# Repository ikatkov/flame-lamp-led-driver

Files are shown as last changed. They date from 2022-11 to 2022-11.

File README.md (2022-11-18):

# (Power) Inductor saturation current tester

~60A max current. Power supply 5-25V.
Based on http://elm-chan.org/works/lchk/report.html

You will need an oscilloscope to take measurements.

# Theory

Once powered, the capacitor bank charges up. The circuit fires off a variable-width pulse into the MOSFET gate. MOSFET turns ON and short-circuits the inductor to the capacitor power bank. The current starts to rise linearly until the saturation point is reached. Once the inductor is saturated, it behaves like an ohmic piece of wire, and the current increases exponentially until the pulse is over, and the MOSFET is switched OFF. Saturation is a knee, not a sharp point. So you have some wiggle room in what current you designate as a "saturation current." Before the saturation point and including the "knee region," inductance will be higher than labeled. Once saturated sufficiently - inductance will drop.

Commercial manufacturers pick the point where a power inductor loses 20-30% of its labeled inductance. One can safely operate inductors at x1.3-1.5 their knee point.

You take voltage drop measurements across 0.1 Ohm resistor, multiply by 10 and get current in Amps flowing through your inductor under test. `I = V*10`

You can also compute actual inductance be taking your supply voltage and dividing by the voltage slope. 
`L = Vs * Δt / ΔI`. 

# Practical operations

See "sort-of" instructions video https://www.youtube.com/watch?v=3Y_WcuIenSM
Notice that although their PCB is labeled 1us..50us. It's impossible to get a positive pulse width of less than 10uS with NE555. One can replace it with other astable timers ICs, but you need a separate MOSFET driving circuitry. NE555 raising and falling times ~350ns, with a max current of 200mA, which is not enough to quickly switch power MOSFETs ON/OFF. The MOSFET will be in its linear region for some time. Therefore the trigger pulse is set to ~50Hz, letting MOSFET cool down between pulses. Also, notice that the current sense shunt, capacitor bank ESR and traces resistance limits max current to ~56A.
You would want to rig some sort of replacable solder-pads on the top of the PCB, so you can finger-press small SMD inductors to it and solder large ones to take measurements. There are header holes for this.

* Unplug the power
* Turn the potentiometer all the way counterclockwise. Set the duration selector jumper to the shortest range. 
* Connect oscilloscope probes
* Plug the power
* Look at the oscilloscope
* Turn the potentiometer clockwise (increasing the pulse width) until you see the saturation knee
* If you still see a linear ramp, unplug, change the duration selector jumper to the next position, turn the potentiometer all the way counterclockwise and repeat
* Take measurements

Knee

Schematic

# Manufacturing

PCB
Top view
[PCB STEP model](main.step)

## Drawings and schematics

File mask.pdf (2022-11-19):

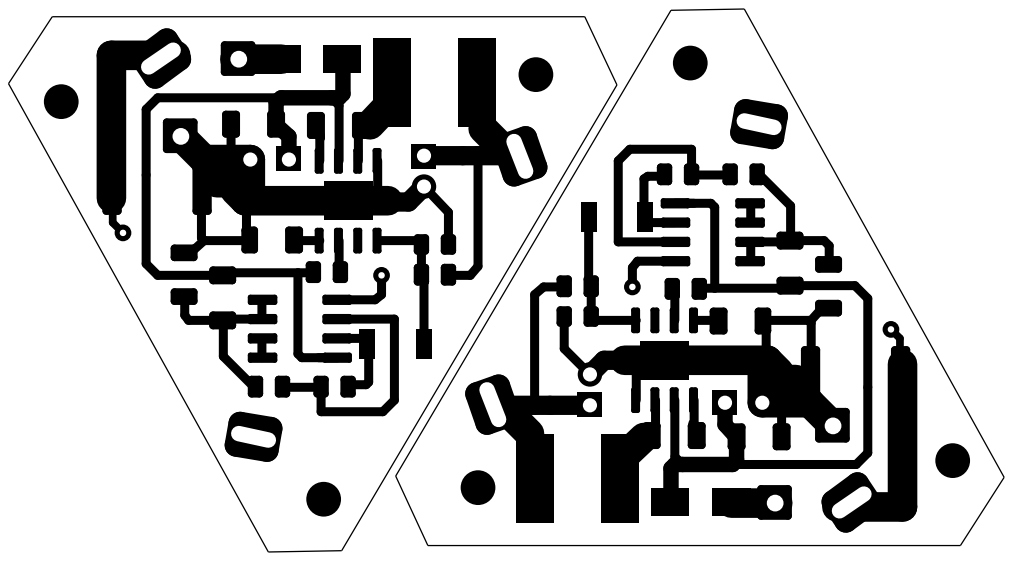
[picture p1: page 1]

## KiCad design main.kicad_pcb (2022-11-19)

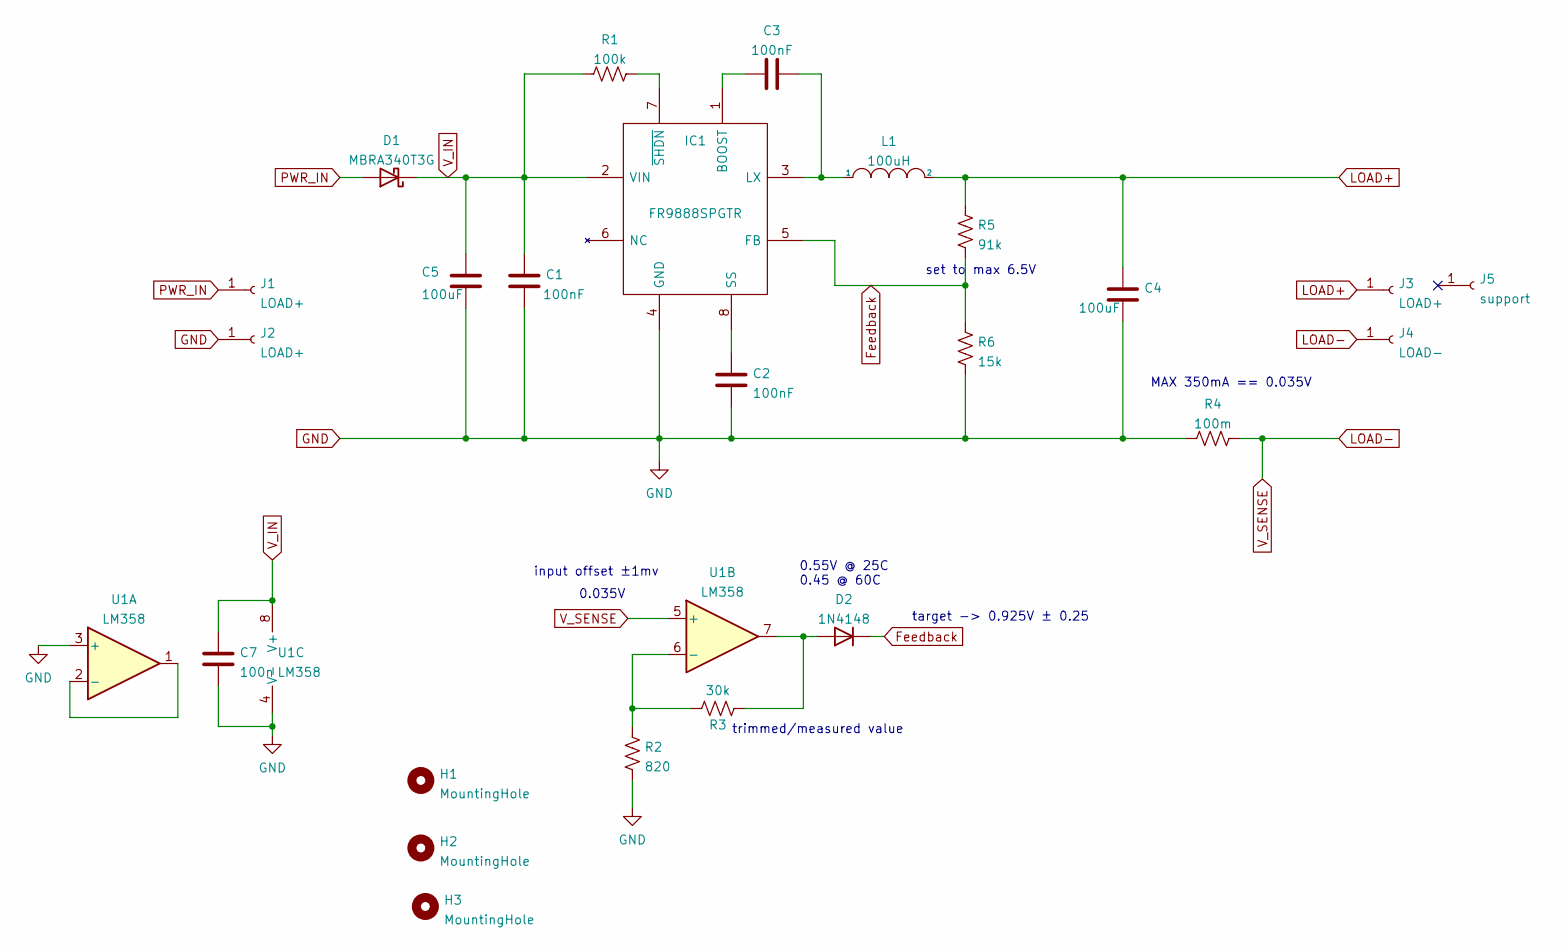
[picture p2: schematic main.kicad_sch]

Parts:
C1, C2, C3: 100nF; C_1206_3216Metric
C4: 100uF; CP_Radial_D5.0mm_P2.00mm
C5: 100uF; CP_Radial_D6.3mm_P2.50mm
C7: 100n; C_1206_3216Metric
D1: MBRA340T3G; D_SMA
D2: 1N4148; D_4148_SMD
H1, H2, H3: MountingHole; MountingHole_2.2mm_M2
IC1: FR9888SPGTR; SOIC-8-1EP_3.9x4.9mm_P1.27mm_EP2.514x3.2mm; Manufacturer_Part_Number FR9888SPGTR
J1, J2: LOAD+; SolderWire-0.5sqmm_1x01_D0.9mm_OD2.3mm
J3: LOAD+; SolderWire-slot
J4: LOAD-; SolderWire-slot
J5: support; SolderWire-slot
L1: 100uH; L_Taiyo-Yuden_NR-60xx_HandSoldering
R1: 100k; R_0805_2012Metric
R2: 820; R_0805_2012Metric
R3: 30k; R_0805_2012Metric
R4: 100m; R_2512_6332Metric
R5: 91k; R_0805_2012Metric
R6: 15k; R_0805_2012Metric
U1: LM358; SOIC-8_3.9x4.9mm_P1.27mm

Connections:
Feedback: D2.1 (K), IC1.5 (FB), R5.1, R6.2
GND: C1.2, C2.2, C4.2, C5.2, C7.2, IC1.4 (GND), J2.1, R2.2, R4.1, R6.1, U1.3 (+), U1.4 (V-)
LOAD+: C4.1, J3.1, L1.2, R5.2
LOAD-: J4.1, R4.2, U1.5 (+)
unnamed: C2.1, IC1.8 (SS)
unnamed: C3.1, IC1.3 (LX), L1.1
unnamed: C3.2, IC1.1 (BOOST)
unnamed: D2.2 (A), R3.2, U1.7
unnamed: IC1.7 (~SHDN), R1.2
unnamed: R2.1, R3.1, U1.6 (-)
unnamed: U1.1, U1.2 (-)
PWR_IN: D1.2 (A), J1.1
V_IN: C1.1, C5.1, C7.1, D1.1 (K), IC1.2 (VIN), R1.1, U1.8 (V+)

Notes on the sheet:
set to max 6.5V
0.035V
0.55V @ 25C 0.45 @ 60C
MAX 350mA == 0.035V
target -> 0.925V ± 0.25
trimmed/measured value
input offset ±1mv

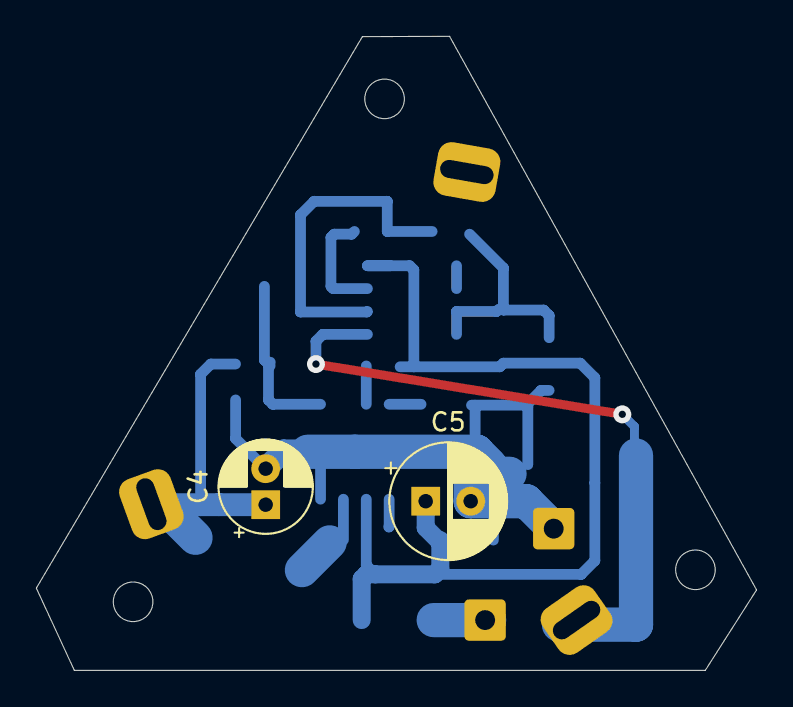
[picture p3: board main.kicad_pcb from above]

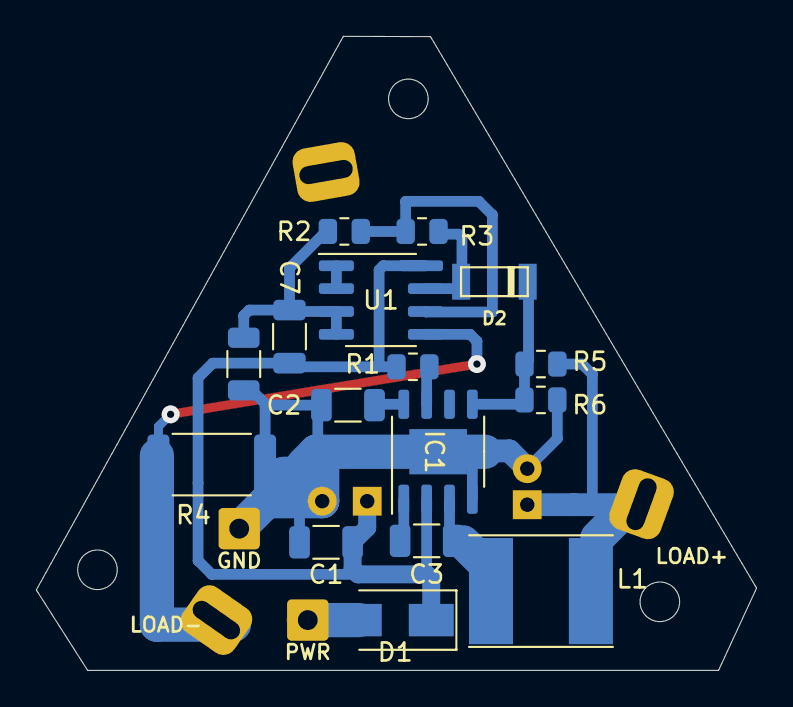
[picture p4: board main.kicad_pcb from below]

Board: 4 copper layers, 40.0 x 35.2 mm, 25 parts (21 on the bottom side), 13 nets.
